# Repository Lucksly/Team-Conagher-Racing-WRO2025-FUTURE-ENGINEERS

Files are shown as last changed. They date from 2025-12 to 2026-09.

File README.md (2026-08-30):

Welcome To Team Conagher Racing's Virtual Garage
===
Now before we get into anything, who are we?

We are Conagher Racing, a three-man team from the Benjamin Harrison Highschool in Cayey, Puerto Rico with a passion for robots. We participate in the Future Engineers category of the World Robot Olympiad and we both strive to reach great places in the near future.

Now that we've got that out of the way, let's explain a few things before we go on:

The robot's naming scheme:
Now in the documentation you'll see him commonly refered to as V. Juan or THE MACHINE or a similar name, well these all refer to different things like:

V.(funny word play on the version number), S.P. V.(funny word play):
This is refering to version one of the robot and is how we'll be talking about every specific version of our robot, it's organized in a very specific way:

S.P. 
This is the controller or procesor that is being used
    
V.
The word version

(funny word play)
This is the actual version of our robot and it's meant to be a funny way of saying the number of version we are on, Juan for one, Chew for two, etc.

THE MACHINE
This refers to the robot in a generic form, not a specific version but it's still a valid name.

So, we've gotten that out of the way, what's inside each folder:

[The About Us](About%20us/README.md) folder just has a quick description of the team along with the 2 pictures of us.

[The 3D Models](3D%20Models/README.md) folder contains the sources for the 3D models used on THE MACHINE.

[The About THE MACHINE](About%20THE%20MACHINE/README.md) folder contains all the pictures along side a description of THE MACHINE.

[The secret sauce](The%20secret%20sauce/README.md) folder contains all of the programs that have been made for THE MACHINE.

[The Schematics and Diagrams](Schematics%20and%20Diagrams/README.md) folder contains, as the name suggests, schematics and diagrams of THE MACHINE.

Btw, we have a [Youtube Channel](https://www.youtube.com/@TeamConagherRacing) where we might post stuff so stay tunned.

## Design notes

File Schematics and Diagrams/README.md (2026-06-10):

Diagrams
==

Main wiring diagram:

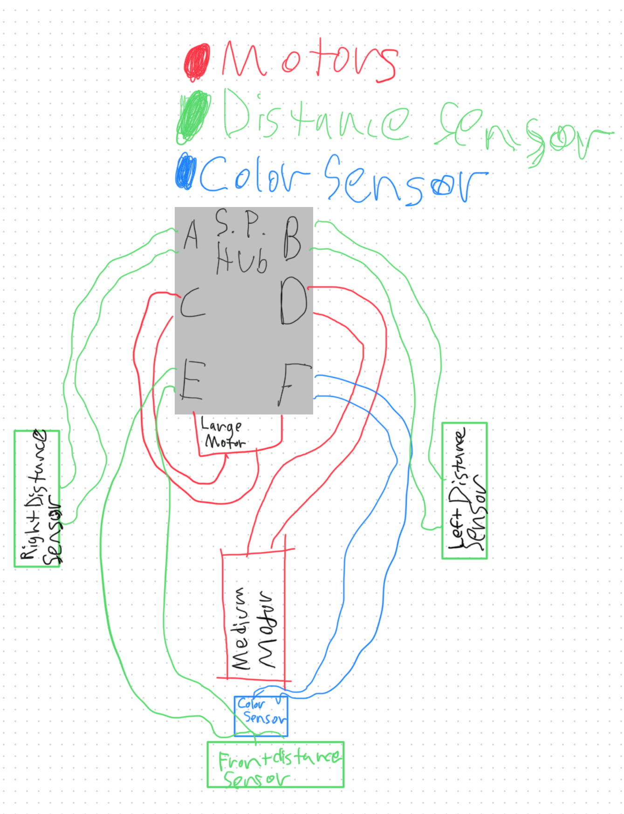
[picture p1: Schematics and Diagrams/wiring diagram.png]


Program function diagram:

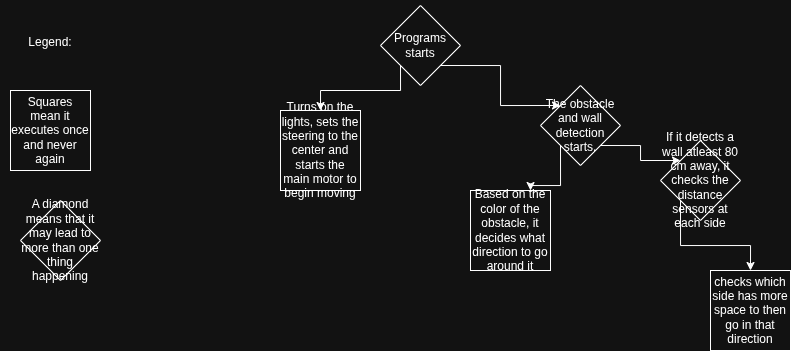
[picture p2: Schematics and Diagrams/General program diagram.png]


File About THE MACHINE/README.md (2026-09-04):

About THE MACHINE
====
V. Juan:

This little goofy guy is V. Juan, our first robot for the WRO Future Engineers category.

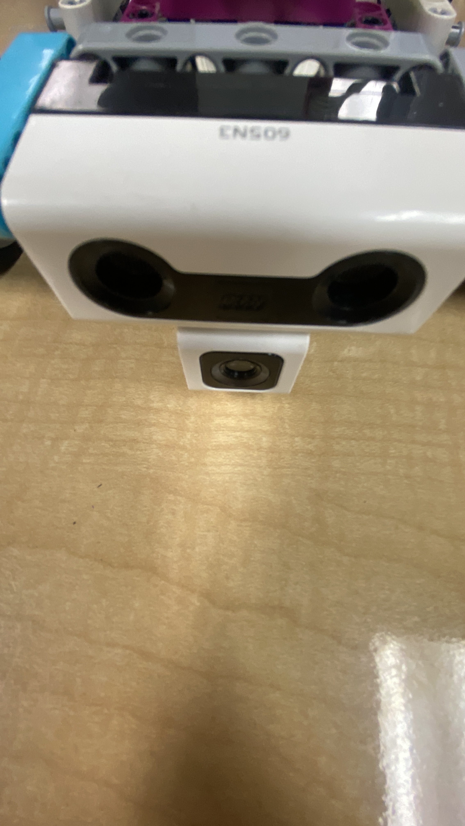
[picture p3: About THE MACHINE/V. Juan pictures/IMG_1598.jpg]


He's on some sick 52 mm by 26.4 mm 7 spoke rims for 1/10 scale rc cars off Aliexpress which can be bought here (https://www.aliexpress.com/i/1005010007257755.html P.S. DON'T BUY REAL CAR RIMS FROM ALIEXPRESS THEY WILL SHATTER ON YOU):
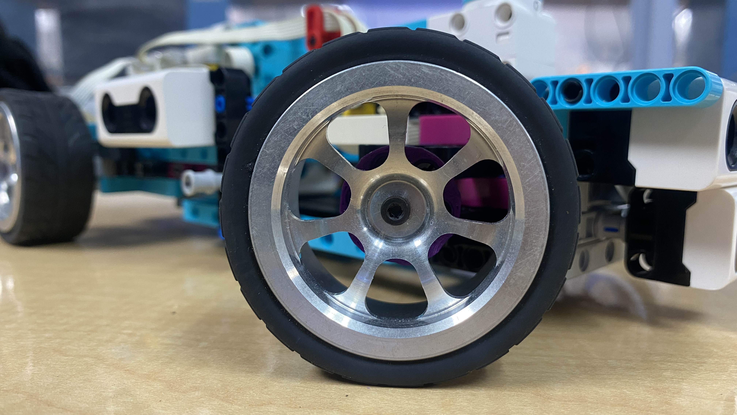
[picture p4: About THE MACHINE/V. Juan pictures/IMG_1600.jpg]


He measures in at 8.8 cm in height, 19.2 cm in width and 28.8 cm depth and weighs in at 793.78 grams
<table>
    <tr>
        <td>
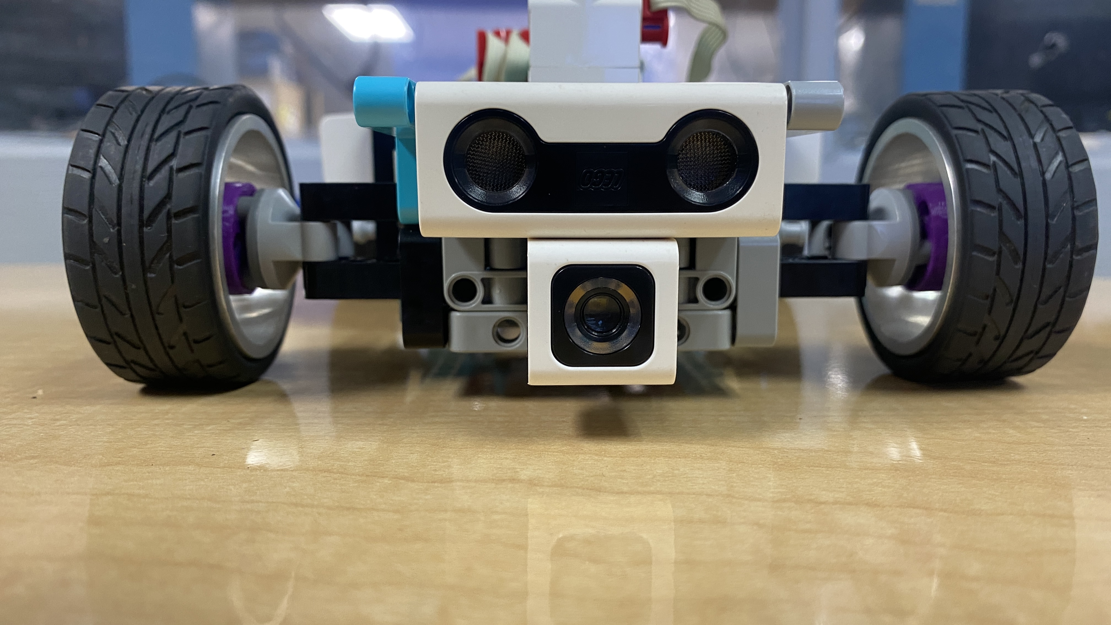
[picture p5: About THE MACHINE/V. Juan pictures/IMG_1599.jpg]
             Front
        </td>
        <td>
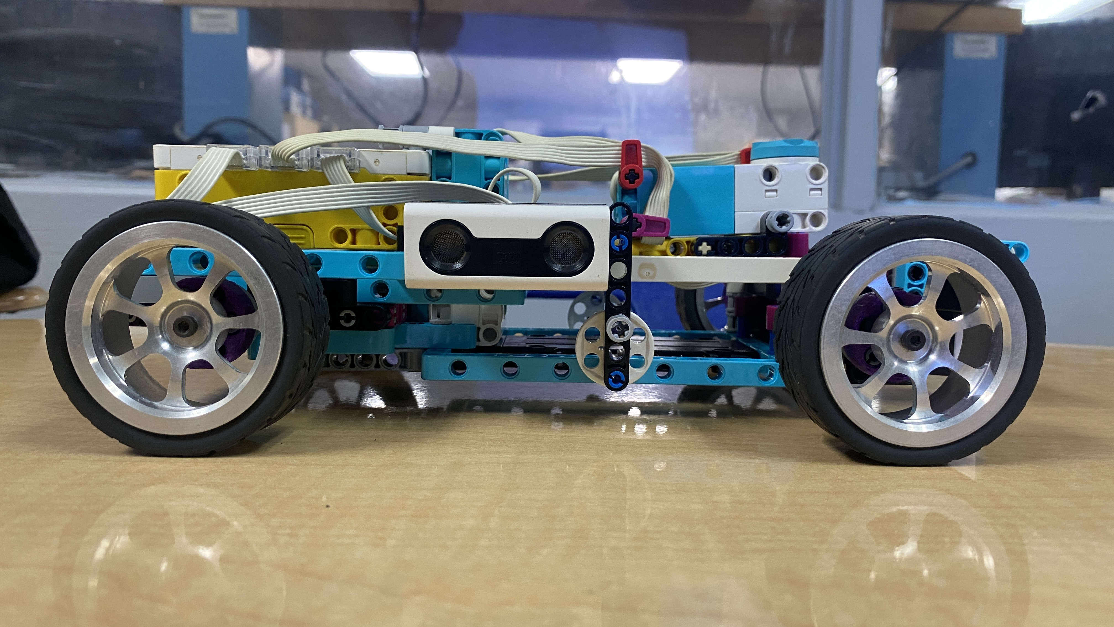
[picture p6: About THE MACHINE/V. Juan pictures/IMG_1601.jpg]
             Right Side
        </td>
                <td>
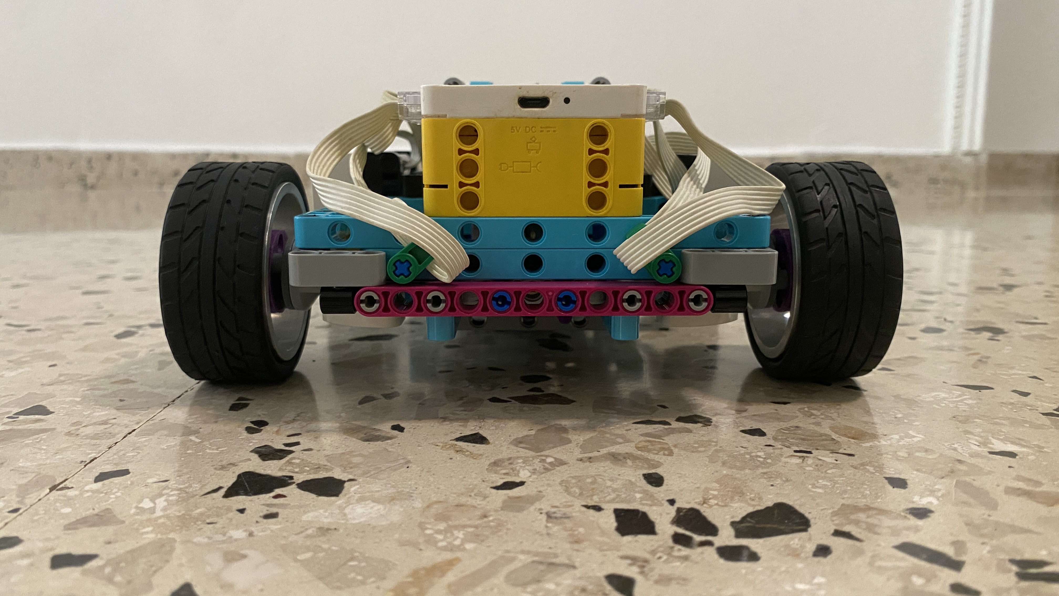
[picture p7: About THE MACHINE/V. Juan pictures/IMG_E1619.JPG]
         Rear
        </td>
    </tr>
    <tr>
        <td>
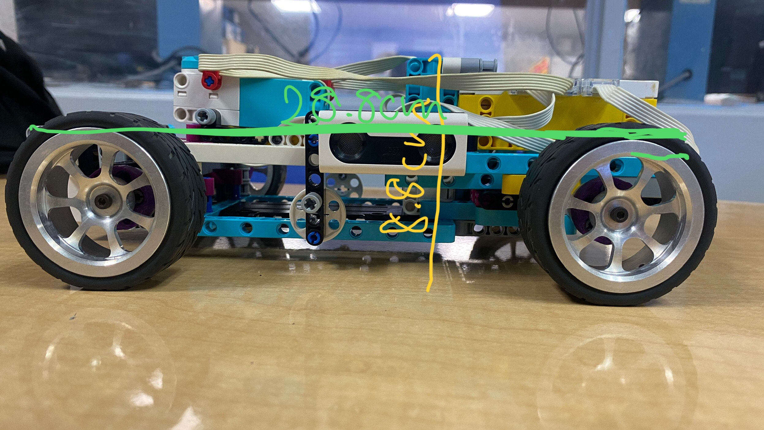
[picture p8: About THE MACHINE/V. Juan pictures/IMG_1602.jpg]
             Left Side w/ measurements
        </td>
        <td>
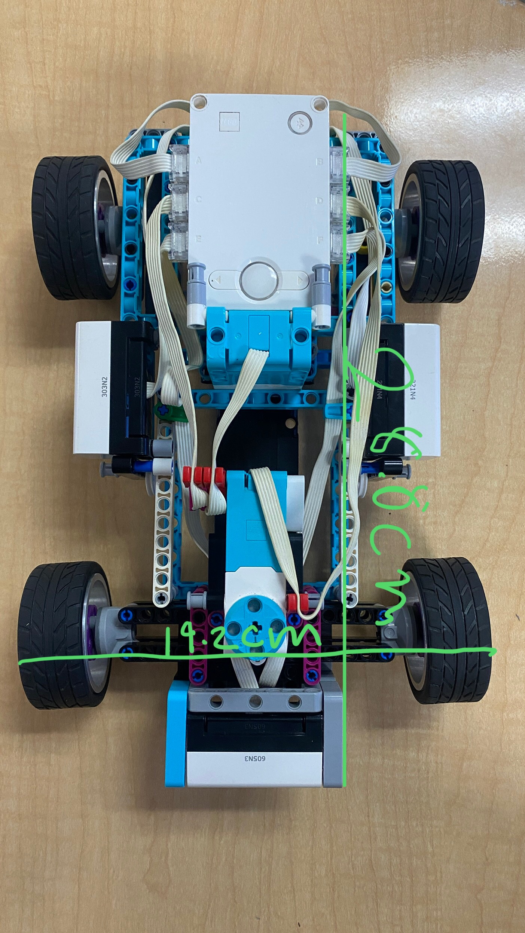
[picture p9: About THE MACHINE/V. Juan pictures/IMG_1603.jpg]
             Top Down w/ measurements
        </td>
                <td>
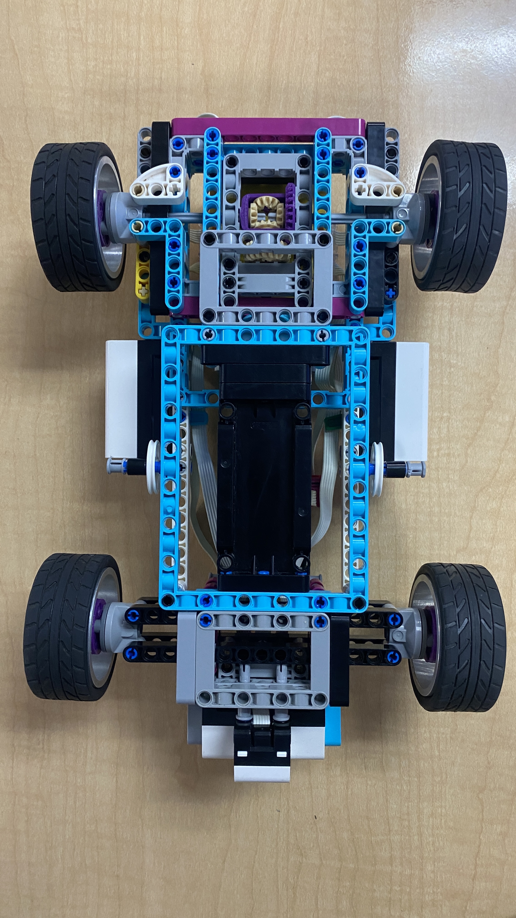
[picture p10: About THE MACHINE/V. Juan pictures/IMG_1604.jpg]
         Bottom Up
        </td>
                <td>
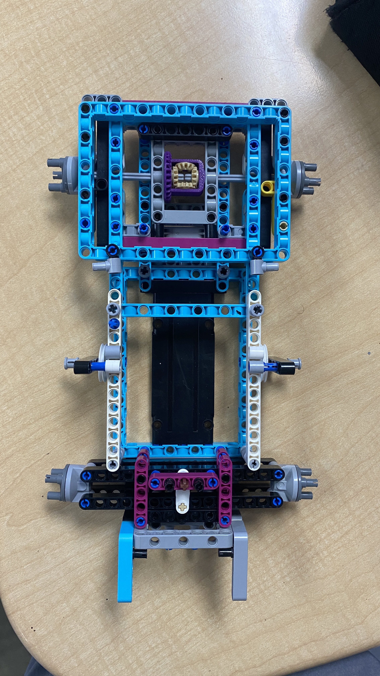
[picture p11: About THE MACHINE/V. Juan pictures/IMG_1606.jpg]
         Chasis without electronic components    
    </tr>
</table>

He's composed of the following electronic parts:
<table>
    <tr>
        <td>
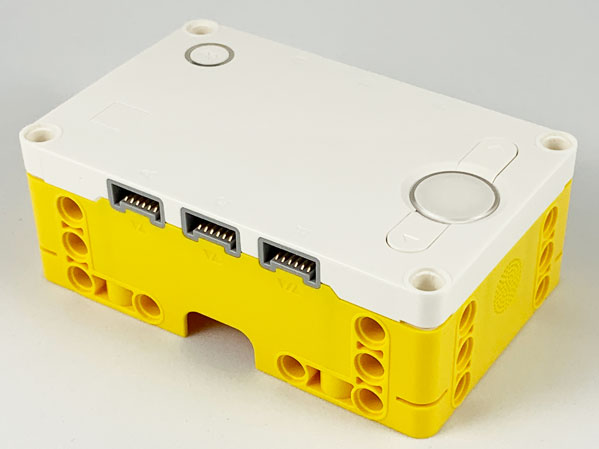
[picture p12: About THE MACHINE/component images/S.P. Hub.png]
             Lego Spike Prime Hub
        </td>
        <td>
             Placed at the back of THE MACHINE atop the differential, it's the heart of our MACHINE.
        </td>
                <td>
        </td>
    </tr>
    <tr>
        <td>
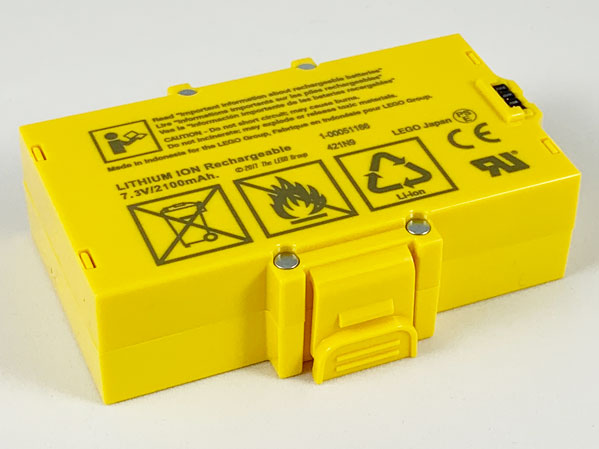
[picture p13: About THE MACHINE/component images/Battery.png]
             Lego Spike Prime Hub Battery
        </td>
        <td>
            A lithium ion recharable battery that powers the entire robot at 7.3v for 2100mAh or 15.4Wh which we have found as enough for now
        </td>
                <td>
    </tr>
    <tr>
        <td>
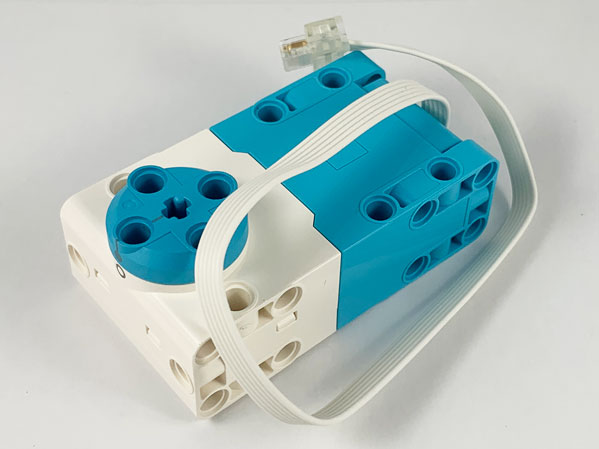
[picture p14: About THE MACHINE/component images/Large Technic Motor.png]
             Lego Spike Prime Large Motor
        </td>
        <td>
            Placed in the middle of THE MACHINE to drive it via a technic axle connected to the differential, according to Lego, it generates 8 Ncm of torque at 135 RPM and consumes 430 mA at "maximum efficiency", thanks to the 20 tooth gear at the end of the Technic axle and the 28 tooth gear on the differential, this create an increase in torque at the expense of speed which results in the wheels getting 11.2 Ncm of torque at 96.42 RPM. 
        </td>
                <td>
    </tr><tr>
        <td>
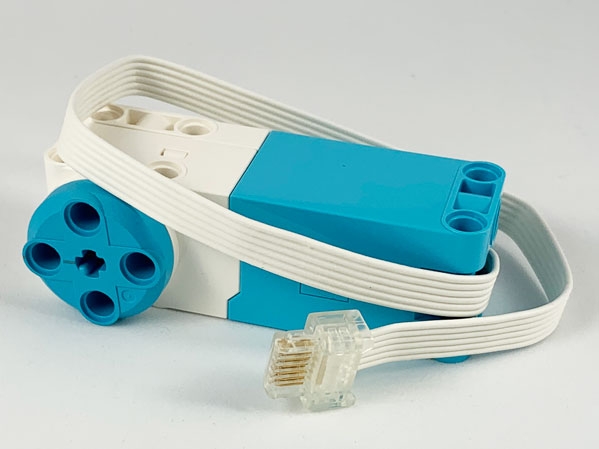
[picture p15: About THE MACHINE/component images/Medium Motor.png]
             Lego Spike Prime Medium Motor
        </td>
        <td>
            This motor is placed at the front of THE MACHINE, atop the steering arms and is used for steering, it generates 3.5 Ncm of torque at 135 RPM and consumes 280mA according to Lego
        </td>
                <td>
    </tr><tr>
        <td>
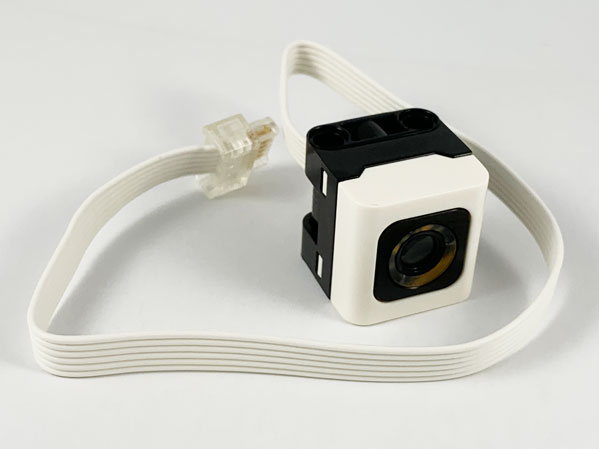
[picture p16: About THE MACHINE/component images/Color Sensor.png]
             Lego Spike Prime Color Sensor
        </td>
        <td>
            Placed at the front of THE MACHINE below the front Ultrasonic distance sensor it's meant to identify the obstacles up to 4 to 6 cm from our testing and a sample rate of 100hz to relay that information to the hub to then decide what to do.
        </td>
                <td>
    </tr><tr>
        <td>
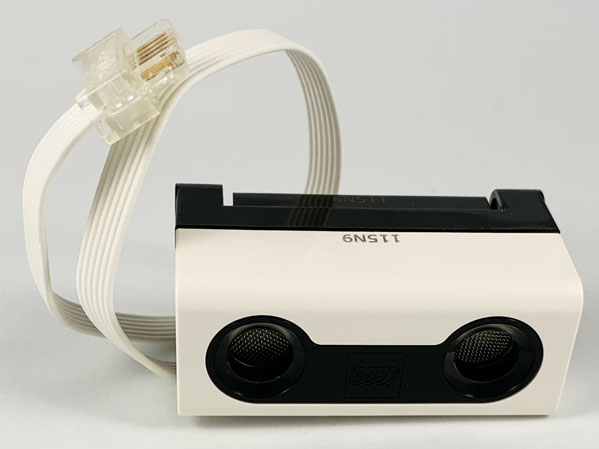
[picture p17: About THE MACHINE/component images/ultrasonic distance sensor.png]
             Lego Spike Prime Ultrasonic Distance Sensor
        </td>
        <td>
            One placed at the front and one at both left and right sides for wall detection and obstacle avoiding, it can detect objects for 200 cm and has a sample rate of 100 Hz
        </td>
                <td>
    </tr>
</table>
Source: https://education.lego.com/en-us/product-resources/spike-prime/downloads/technical-specifications/ 

V. Chew:

This, is THE MACHINE'S evolved state, V. Chew, the changes are few but practical, mainly, he's shorter and is now programed in micropython via pybricks.

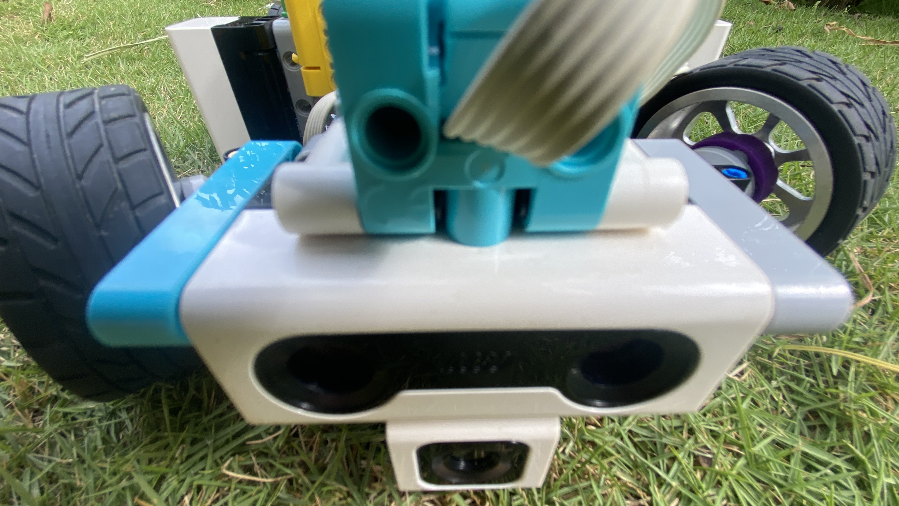
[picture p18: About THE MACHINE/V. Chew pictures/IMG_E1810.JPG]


He measures in at 24.5 cm long, 19.5 cm wide and 10.5 cm tall he's equiped with the same wheels and electronic components as V. Juan, so they aren't that different from one another.

<table>
    <tr>
        <td>
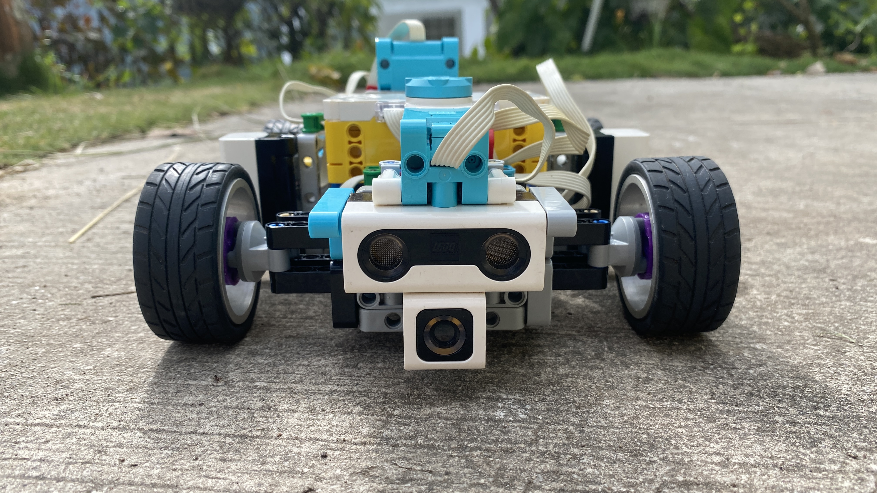
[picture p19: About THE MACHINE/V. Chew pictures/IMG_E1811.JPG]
             Front
        </td>
        <td>
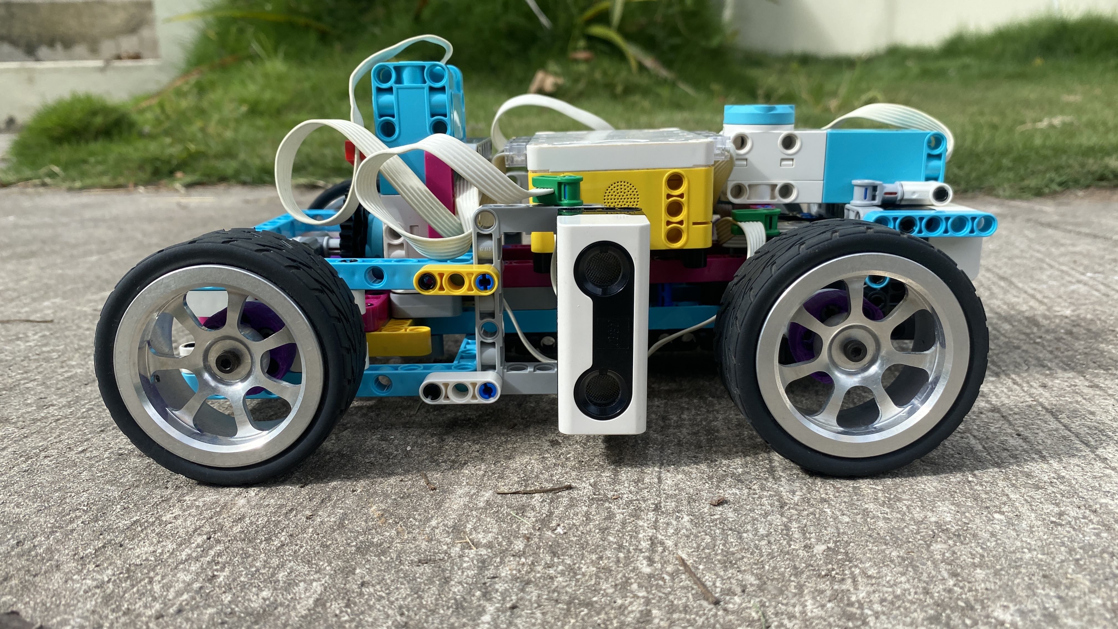
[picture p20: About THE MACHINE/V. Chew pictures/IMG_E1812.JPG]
             Right Side
        </td>
                <td>
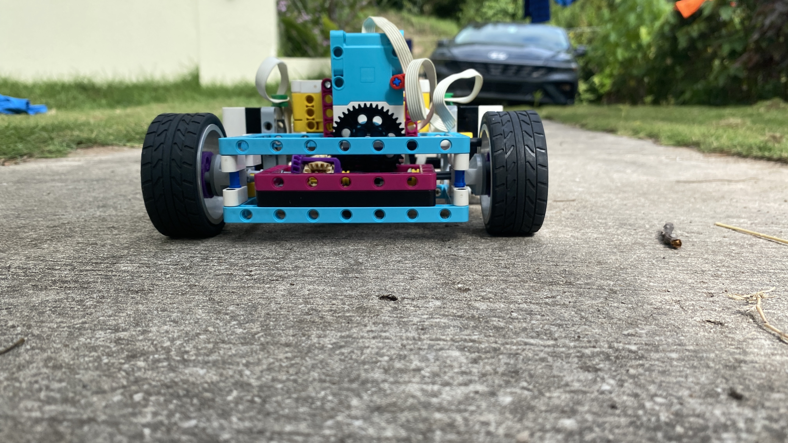
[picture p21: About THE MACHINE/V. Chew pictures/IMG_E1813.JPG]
         Rear
        </td>
    </tr>
    <tr>
        <td>
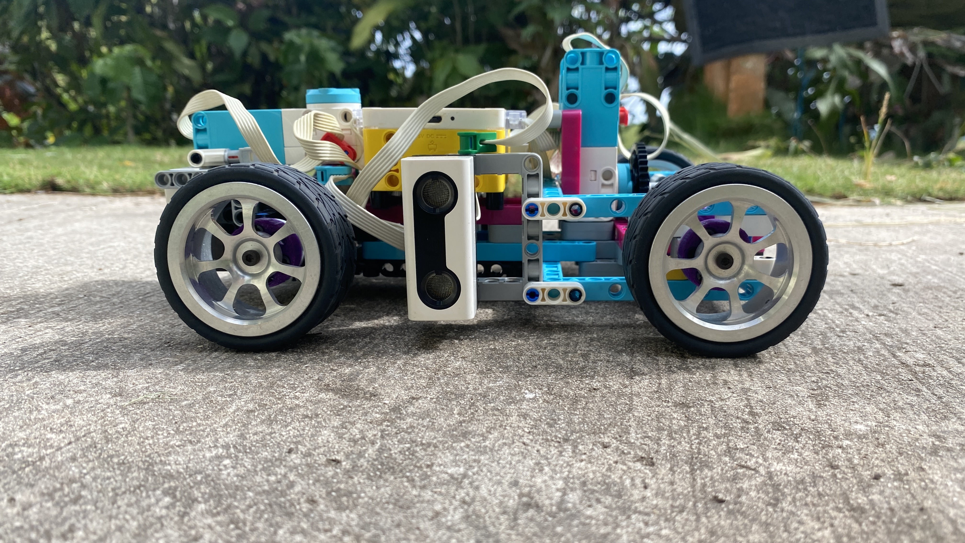
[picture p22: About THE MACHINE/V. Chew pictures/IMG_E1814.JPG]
             Left Side 
        </td>
        <td>
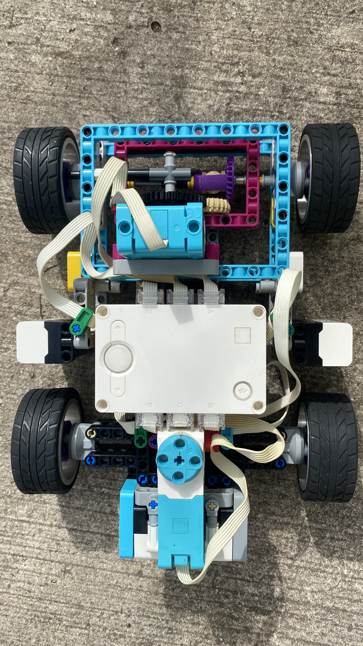
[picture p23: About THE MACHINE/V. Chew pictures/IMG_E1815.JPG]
             Top Down 
        </td>
                <td>
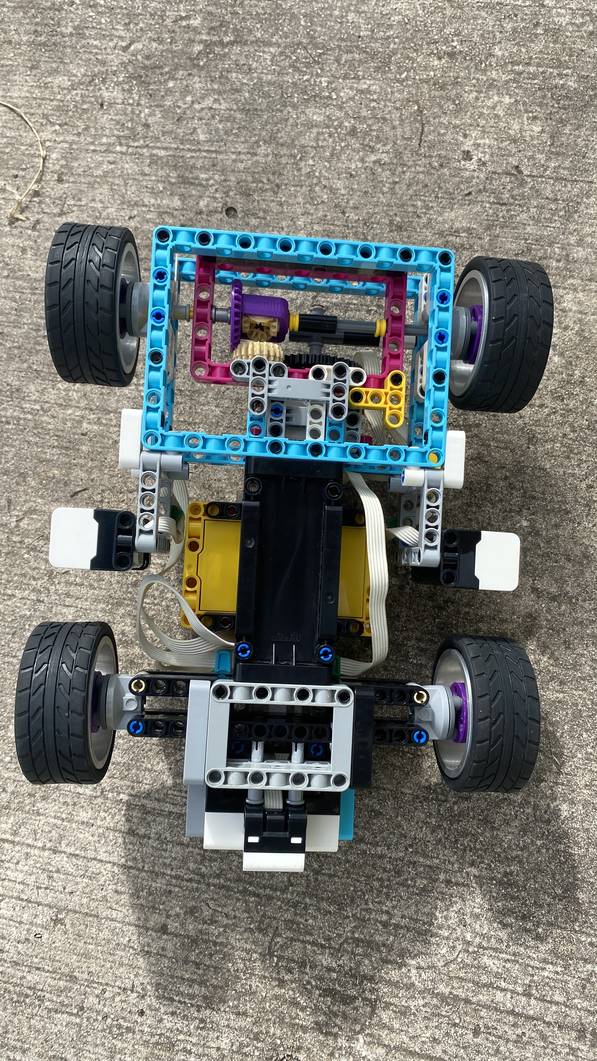
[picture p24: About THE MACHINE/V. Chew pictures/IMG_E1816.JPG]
         Bottom Up
        </td>  
    </tr>
</table>

V. Chew Upgrades
===
The measurements haven't changed, although some components have been changed:

Wheels:
    
We now use 3d printed Enkei RPF1 rims for weight saving purposes which can be found [here](https://cults3d.com/en/3d-model/game/1-10-rc-rim-rpf1)

Electronics:

We have removed the Lego Spike Color Sensor due to its limited range, in its place originally there was going to be a [Cytron Maker Pi RP2040](https://www.cytron.io/p-maker-pi-rp2040-simplifying-robotics-with-raspberry-pi-rp2040) but the one we had sourced from our coach had a missing grove port, and we had attempted to use a different grove port to have [UART](https://docs.micropython.org/en/latest/reference/glossary.html#term-UART) but the GP0 pad started lifting from the side that was connected to the trace so we decided to instead use a [Raspberry Pi Pico 2](https://www.raspberrypi.com/products/raspberry-pi-pico-2/) provided by our coach, which we might mount to the robot using Cytron's [Robo Pico](https://www.cytron.io/p-robo-pico) but also means that THE MACHINE'S full name is now S.P.P2. V. sChew, but we just call him V. Chew cause why not. Currentlly in testing we've been using the Pico2 with a [APDS-9960](https://learn.sparkfun.com/tutorials/apds-9960-rgb-and-gesture-sensor-hookup-guide/all) conmected via [I2C](https://docs.micropython.org/en/latest/library/machine.I2C.html) which was also provided by our coach although we are considering a camera so we can have higher accuracy for detecing obstacles and the parking.

Prototype:

V. Chew R(udolf), in this version of V. Chew, we have managed to get the Lego Spike Hub to communicate effectively with the [Cytron Maker Pi RP2040](https://www.cytron.io/p-maker-pi-rp2040-simplifying-robotics-with-raspberry-pi-rp2040), which now rests under the Hub, hopefully, will give it a chance at revival as a part of our machine. This version still uses our new color sensor, the [APDS-9960](https://learn.sparkfun.com/tutorials/apds-9960-rgb-and-gesture-sensor-hookup-guide/all). Besides that, we've called this prototype version of V. Chew, V. Chew R(udolf) 'cause the [APDS-9960](https://learn.sparkfun.com/tutorials/apds-9960-rgb-and-gesture-sensor-hookup-guide/all) color sensor, which is RED, is placed right in the front of our distance sensor, makin' it look like a Rudolf's nose. The reason we put the color sensor there is to make use of the distance sensor's LED light to further increase our color sensor's accuracy.


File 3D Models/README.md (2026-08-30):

3D Models taken off the internet
===
Differential:
https://www.printables.com/model/36860-lego-differential-v2

Enkei Rpf1:
https://cults3d.com/en/3d-model/game/1-10-rc-rim-rpf1

3D Models made In House
===
1/10 Scale RC Car to Lego Technic Wheel Hub
It's currently printed in Dremel's PLA plastic on a Dremel 3D45 with the technic wholes drilled out to fit technic pins correctly:
!\[Description\](wheel adapter picture.jpg)

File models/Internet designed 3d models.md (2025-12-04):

Differential:
https://www.printables.com/model/36860-lego-differential-v2

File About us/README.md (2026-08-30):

About Us
===

We are Conagher Racing, a three-man team from Puerto Rico with a passion for robots. We participate in the Future Engineers category of the World Robot Olympiad and we both strive to reach great places in the near future.

Guy on the left, Luis:
Hi, I'm Luis D. Aponte Colón, I the mechanical work on THE MACHINE, along with most of the programing up to version 9 along with most of the documentation, we're currently working on teaching César to program so I can focus on mechanical work and documentation, but it's all from me for now.

Guy on the right, César:
Hello, im César J. García Ortiz, I am the rookie programmer of Conagher Racing, and am tasked mostly with coming up with ideas or strategies in where our robot could prevail in competitions. Im open minded and not afraid to show my perspective on things. Well, uh, ththat's me!

Guy who current isnt in any photos(pretend he's next to César or something), David:
(Note, this is supposed to be writen by David but he isnt here rn so Luis filled in)He's the senior programmer of the team when it comes to pybricks, since he's now going to college he might not be present in all the competitions but he's here more as an in team mentor for César in the programming aspect.

!\[Description\](1st place at robinson.jpg)

!\[Description\](IMG_0531.jpg)

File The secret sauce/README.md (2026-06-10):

Secret Sauce
====

As the name suggest, it's the secret sauce to the robots functionalaty.

Explicative diagram to the code:



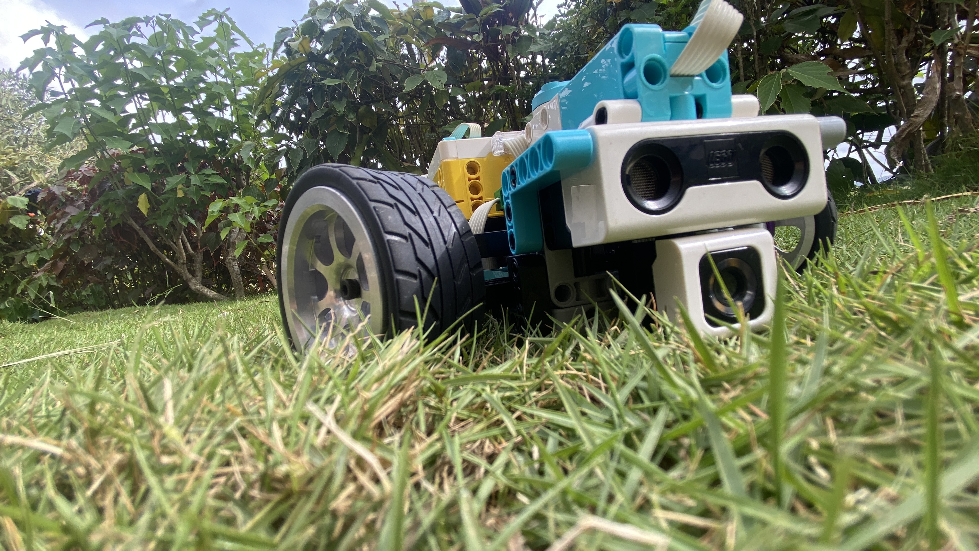
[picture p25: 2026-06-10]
About THE MACHINE/V. Chew pictures/IMG_E1808.JPG

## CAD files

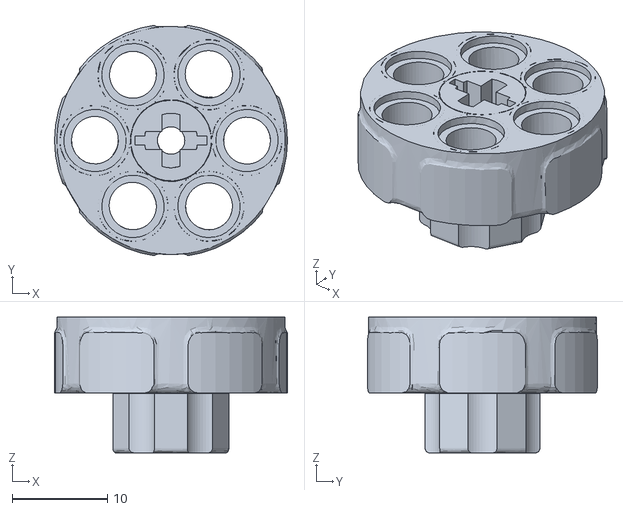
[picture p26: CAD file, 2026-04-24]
3D Models/wheel adapter.stl
24.5 x 24.2 x 14.3

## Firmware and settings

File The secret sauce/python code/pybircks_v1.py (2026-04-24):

# pybricks blocks file:{"blocks":{"languageVersion":0,"blocks":[{"type":"blockGlobalSetup","id":"bjK,wS1MYO7aiYkFSwd{","x":-21,"y":99,"deletable":false,"next":{"block":{"type":"variables_set_prime_hub","id":"=cA{2d;~)y2zO|~D21?5","extraState":{"optionLevel":0},"fields":{"VAR":{"id":";JUBNhY%jB0N20=UBnQ+"}},"next":{"block":{"type":"variables_set_car","id":"9Ci9]dSlm/Xg78h7wF(|","extraState":{"optionLevel":0},"fields":{"VAR":{"id":"LH$Q/wW9%ic#ox]r8JqE"}},"inputs":{"VAR":{"shadow":{"type":"variables_get_motor_device","id":"|BUV+x4cAKWO0J/,xk`B","fields":{"VAR":{"id":"7;0v;%!nBVec|Y?Jj*Xl","name":"steering","type":"Motor"}}}},"VAR2":{"shadow":{"type":"variables_get_motor_device","id":"[`q,-S(ERm(H4`ID!=6H","fields":{"VAR":{"id":"9PRB#~pz=zeM}H!;vYZ)","name":"driveshaft","type":"Motor"}}}}},"next":{"block":{"type":"variables_set_motor","id":"N:Xs=lb?fi6#`/QBk5{x","fields":{"VAR":{"id":"9PRB#~pz=zeM}H!;vYZ)"}},"inputs":{"PORT":{"shadow":{"type":"blockParametersPort","id":".(BJ.%rcBad%5-FWp@%b","fields":{"NAME":"C"}}},"POSITIVE_DIRECTION":{"shadow":{"type":"blockParametersDirection","id":"c;:O(S2HP*@X[xK1G05Z","fields":{"SELECTION":"Direction.CLOCKWISE"}}}},"next":{"block":{"type":"variables_set_color_sensor","id":"{xF{=E7LO!O/Os}Ou`+}","extraState":{"optionLevel":0},"fields":{"VAR":{"id":"L;?S6?oT,;,Re;4o!vx6"}},"inputs":{"PORT":{"shadow":{"type":"blockParametersPort","id":"aNVj$?}2Owz!R:NL$^8@","fields":{"NAME":"F"}}}},"next":{"block":{"type":"variables_set_ultrasonic_sensor","id":"!6/.m,~esa;n9=)=be6!","fields":{"VAR":{"id":"21v8;Vdb:d`x^D|uwq~?"}},"inputs":{"PORT":{"shadow":{"type":"blockParametersPort","id":".:]t7z)B1-{XI1M)k%}@","fields":{"NAME":"A"}}}},"next":{"block":{"type":"variables_set_ultrasonic_sensor","id":"*M8dP92I?5Tj/Pq!b?SK","fields":{"VAR":{"id":"S%uOA#Ua*Ogu)Ss,6`RH"}},"inputs":{"PORT":{"shadow":{"type":"blockParametersPort","id":"J~vyOUX0ct@!-[l^X,Q6","fields":{"NAME":"B"}}}},"next":{"block":{"type":"variables_set_ultrasonic_sensor","id":"A_0gc}uNc,*)M==ItA=C","fields":{"VAR":{"id":"fwd7qn:3)i))B%6pQyE^"}},"inputs":{"PORT":{"shadow":{"type":"blockParametersPort","id":"/UEYQIrsPP`:IX1+kBBu","fields":{"NAME":"E"}}}},"next":{"block":{"type":"variables_set_motor","id":"SADX+8sVX9g.BcHex6NS","fields":{"VAR":{"id":"7;0v;%!nBVec|Y?Jj*Xl"}},"inputs":{"PORT":{"shadow":{"type":"blockParametersPort","id":"F#q)/Z;~ao/T|Zcy}?zl","fields":{"NAME":"D"}}},"POSITIVE_DIRECTION":{"shadow":{"type":"blockParametersDirection","id":"#RplpL5yj0@xBR:VaT:$","fields":{"SELECTION":"Direction.CLOCKWISE"}}}},"next":{"block":{"type":"variables_setup_any","id":"aN4^I}W5Y;,{R{E;S8fz","fields":{"VAR":{"id":"/@P|$eA2gw8SwgH=1xHp"}},"inputs":{"VALUE0":{"shadow":{"type":"blockMathNumber","id":"_rIHb1NVdo65/7RrB1H!","fields":{"NUM":0}}}}}}}}}}}}}}}}}}}}}}},{"type":"blockGlobalStart","id":"3tJe|AWl0baN(wH9a$@.","x":648,"y":93,"deletable":false,"next":{"block":{"type":"blockCarDrive","id":"3DdH9N_A07%moX-/5)^#","extraState":{"optionLevel":1},"fields":{"METHOD":"CAR_DRIVE_AT_POWER"},"inputs":{"VAR":{"shadow":{"type":"variables_get_car_device","id":"`_`F2-k95jvaN{`hW;wG","fields":{"VAR":{"id":"LH$Q/wW9%ic#ox]r8JqE","name":"car","type":"Car"}}}},"ARG0":{"shadow":{"type":"unit_percent","id":"0rD?UnwW0Zy=kvduF~?f","fields":{"VALUE0":100}}}},"next":{"block":{"type":"blockMotorResetAngle","id":"Z#qNb8C-VXkYy!td-Efd","inputs":{"VAR":{"shadow":{"type":"variables_get_motor_device","id":"nw9^Fr-m4h6(1s=KEfEN","fields":{"VAR":{"id":"7;0v;%!nBVec|Y?Jj*Xl","name":"steering","type":"Motor"}}}},"VALUE0":{"shadow":{"type":"unit_angle","id":"xuQrHWFGrS3zBc%Lak{[","fields":{"VALUE0":0}}}}}}}}}]},"variables":[{"name":"red","id":"GcuC4@_]h|?mek1cPWQR","type":"ColorDef"},{"name":"orange","id":"f/qSkZU46f`LN*upv%zx","type":"ColorDef"},{"name":"yellow","id":"`Q5[9cK;+4bcmHs#K51l","type":"ColorDef"},{"name":"green","id":")~tbA[Z1|vVn;Jcw??[X","type":"ColorDef"},{"name":"cyan","id":"X3W1HeObT6Mf`h)p`?PJ","type":"ColorDef"},{"name":"blue","id":"M83X4Y8B2]/%8SDY%H;j","type":"ColorDef"},{"name":"violet","id":"^SB^g{,yg|bpXC_{UE-^","type":"ColorDef"},{"name":"magenta","id":"~3tc/c`m9wlC7Ht=Ck+#","type":"ColorDef"},{"name":"white","id":"O:onA7mrhJwN}27L9bSm","type":"ColorDef"},{"name":"none","id":"FBX]]TujqB*hy3)d|$_$","type":"ColorDef"},{"name":"prime hub","id":";JUBNhY%jB0N20=UBnQ+","type":"PrimeHub"},{"name":"car","id":"LH$Q/wW9%ic#ox]r8JqE","type":"Car"},{"name":"distance sensor right","id":"21v8;Vdb:d`x^D|uwq~?","type":"UltrasonicSensor"},{"name":"distance sensor left","id":"S%uOA#Ua*Ogu)Ss,6`RH","type":"UltrasonicSensor"},{"name":"distance sensor front","id":"fwd7qn:3)i))B%6pQyE^","type":"UltrasonicSensor"},{"name":"turn 1","id":"/@P|$eA2gw8SwgH=1xHp","type":"Any"},{"name":"color sensor","id":"L;?S6?oT,;,Re;4o!vx6","type":"ColorSensor"},{"name":"driveshaft","id":"9PRB#~pz=zeM}H!;vYZ)","type":"Motor"},{"name":"steering","id":"7;0v;%!nBVec|Y?Jj*Xl","type":"Motor"}],"info":{"type":"pybricks","version":"1.3.2"}}
from pybricks.hubs import PrimeHub
from pybricks.parameters import Direction, Port
from pybricks.pupdevices import ColorSensor, Motor, UltrasonicSensor
from pybricks.robotics import Car

# Set up all devices.
prime_hub = PrimeHub()
color_sensor = ColorSensor(Port.F)
distance_sensor_right = UltrasonicSensor(Port.A)
distance_sensor_left = UltrasonicSensor(Port.B)
distance_sensor_front = UltrasonicSensor(Port.E)
car = Car(steering, driveshaft)
driveshaft = Motor(Port.C, Direction.CLOCKWISE)
steering = Motor(Port.D, Direction.CLOCKWISE)




# The main program starts here.
car.drive_power(100)
steering.reset_angle(0)
